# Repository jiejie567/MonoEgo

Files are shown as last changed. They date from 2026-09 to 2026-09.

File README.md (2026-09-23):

<div align="center">

# MonoEgo
**Monocular Metric Egocentric Demonstration Capture with Passive Wrist Constellations and Sparse Workstation Anchors**

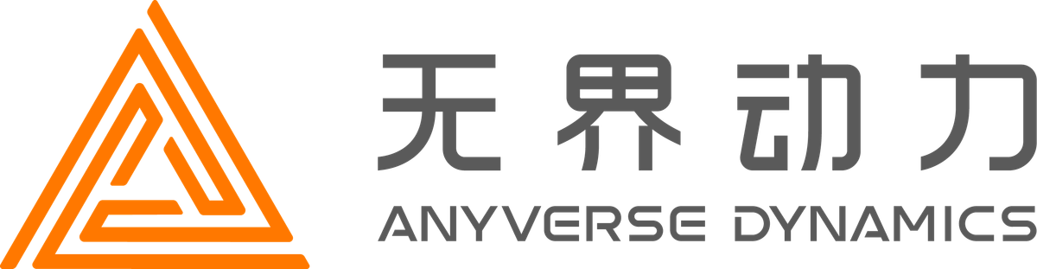
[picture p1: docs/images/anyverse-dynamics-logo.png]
Anyverse Dynamics


[Project homepage](https://jiejie567.github.io/MonoEgo/) · [MonoTag SLAM code](https://github.com/jiejie567/MonoTag-SLAM) · [Hardware](hardware/README.md) · [Results](results/README.md)

</div>

English | [中文](README_CN.md)

MonoEgo records human operations with a head-mounted RGB camera, two passive wrist fixtures and known-size workstation markers. Offline reconstruction produces metric camera and wrist-fixture trajectories from the same image stream.

The fixtures need no battery, IMU or radio. Video and geometric observations share one image clock, avoiding separate tracker-to-video synchronization. Camera and wrist-constellation calibration are still required.

This public repository contains hardware, compact experimental results and representative demonstrations. Public processing code is maintained separately in [MonoTag SLAM](https://github.com/jiejie567/MonoTag-SLAM).

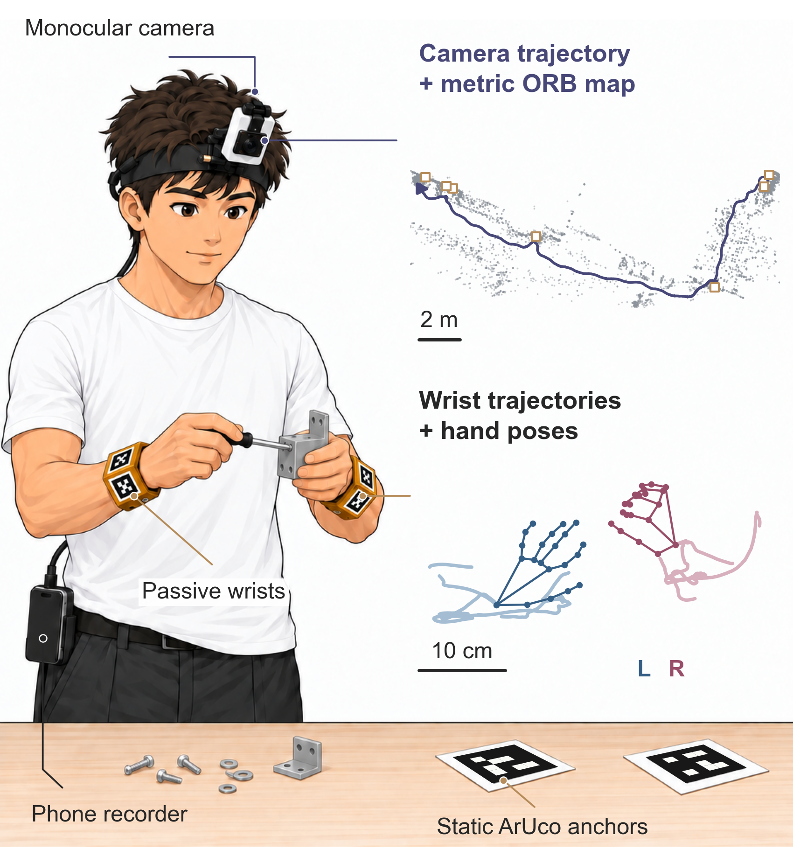
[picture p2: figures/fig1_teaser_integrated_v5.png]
MonoEgo capture system


## From recording to trajectories

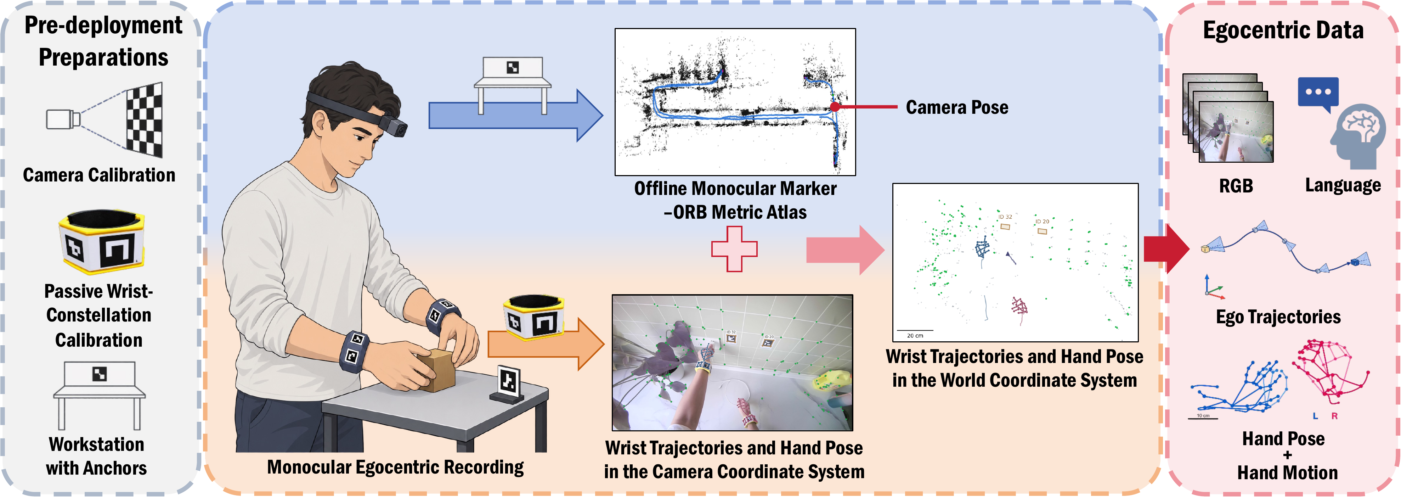
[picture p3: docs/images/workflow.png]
Calibration, recording and offline reconstruction


1. Print and assemble the fixtures and markers; verify physical dimensions.
2. Calibrate camera intrinsics and rigid wrist-marker geometry.
3. Record unchanged RGB video.
4. Run marker-constrained MonoTag reconstruction and optional hand estimation.
5. Inspect validity, trajectories and map events before exporting data.

Known marker dimensions provide metric information. Repeated views constrain scale and map consistency. Offline matching can recover earlier or short-gap poses when sufficient evidence exists. Appearance-edited RGB remains a separate derived product and never feeds back into localization.

## What's included

- [Printable hardware](hardware/README.md): magnetic wrist fixtures, marker sheets and ChArUco target.
- [Example calibrated layouts](hardware/marker_layouts/calibrated_release/): geometry of the specific tested fixtures, not a substitute for calibrating a new assembly.
- [Result sources](results/README.md): camera-reference and stationary-wrist summaries.
- [Representative videos](videos/): stationary-fixture demonstrations with ORB features and trajectories.
- [Processing code](https://github.com/jiejie567/MonoTag-SLAM): calibration, capture, reconstruction, replay and optional export.

## Hardware

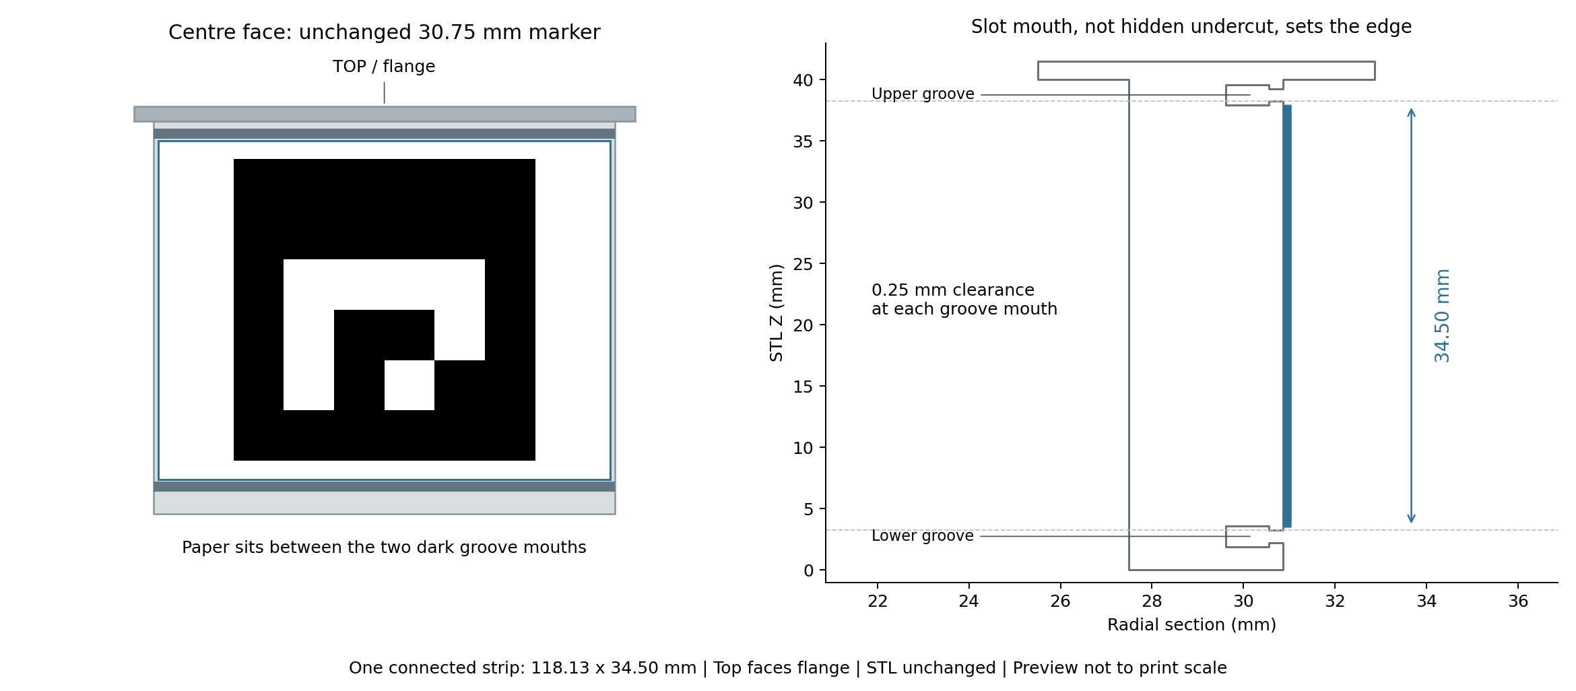
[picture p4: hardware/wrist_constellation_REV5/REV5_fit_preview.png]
REV5 marker placement between two rubber-band grooves


The default design is **REV5: two halves, two rubber-band grooves, no magnet holes**. Download the [STLs and matching marker sheets](hardware/wrist_constellation_REV5/). Add foam padding inside to fit different wrist sizes, and secure the seated halves with one rubber band in each groove. See the [assembly guide](hardware/README.md).

### Camera selection

No particular camera brand or model is required. Prioritize **high frame rate, manual exposure control, and a wide field of view** that covers both hands and enough surrounding scene. High FPS alone does not guarantee sharp frames: set a sufficiently short exposure for the motion and provide adequate light. Keep enough image detail for the wrist markers; a wider view is not automatically better if the markers become too small.

The tested setup uses a WN-L2406K397L global-shutter module, a 2.3 mm f/1.8 M12 lens and 1920 × 1080 recording at 90 FPS. This is a reference configuration, not a required purchase. Global shutter is preferable for rapid camera motion; alternative cameras are not guaranteed to match the reported results. Calibrate the chosen lens and recording mode, and keep focus, crop and stabilization settings unchanged during capture. Reconstruction uses measured intrinsics, not nominal field of view.

Reported capture-side cost was below US$100, excluding the recorder, replacement lens, offline compute, small fasteners and consumables, labour and shipping. This is not the cost of a complete recording and processing system.

Print at actual size, disable fit-to-page, and measure the black square rather than the white paper. Adjust foam thickness for a stable, comfortable fit without excessive pressure. Calibrate each newly assembled constellation.

## Representative videos

### Moving camera, stationary wrist fixtures

[SW-02 video](videos/SW-02_english_orb_trajectories.mp4)

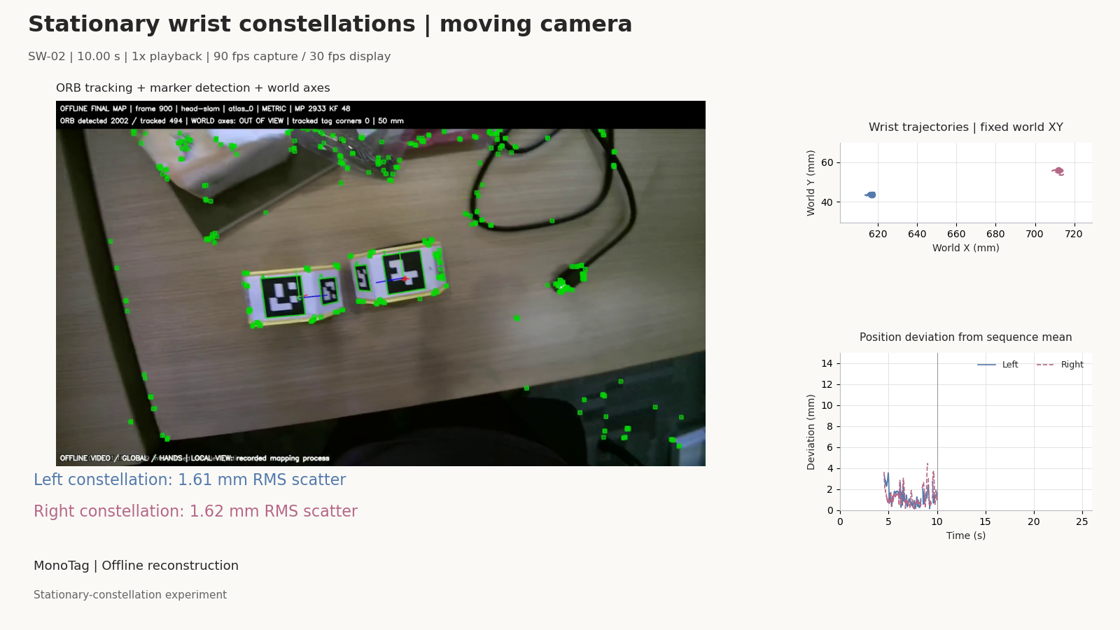
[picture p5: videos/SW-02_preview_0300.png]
SW-02 stationary wrist test


[SW-04 video](videos/SW-04_english_orb_trajectories.mp4)

These examples test whether camera motion appears as motion of a stationary fixture. They measure positional precision, not full dynamic hand-motion accuracy.

## Experimental scope

Camera motion is compared against Odin multisensor odometry as a reference. Metric error uses SE(3) alignment; Sim(3) results are separate because that alignment removes global scale error. Read error together with tracking coverage.

Across four stationary-wrist recordings, per-side RMS scatter was approximately 1.26–2.69 mm. This does not establish equivalent anatomical or dynamic accuracy. See [result sources](results/README.md) for the protocol and tables.

Raw indoor recordings, private screen content, machine-local paths and learned weights are excluded. The unblurred company-video review is not uploaded here.

## Getting started

Follow the [Ubuntu installation guide](https://github.com/jiejie567/MonoTag-SLAM/blob/main/docs/INSTALL.md). Start with SLAM and geometric wrist observations; learned hand inference and training-format export are optional.

## License

Original hardware, layouts, figures, result tables and documentation use [CC BY 4.0](LICENSE.md). Attribute **MonoEgo — Anyverse Dynamics** and indicate changes. Third-party material retains its original license. The company logo is excluded; no trademark or endorsement rights are granted.

Companion code uses GPL-3.0 because it includes modified ORB-SLAM3. Model and dataset terms still apply separately.

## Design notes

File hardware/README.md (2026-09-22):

# Hardware release

REV5 marker placement between rubber-band grooves

## Current design: REV5

Use [REV5 STLs and matching marker files](wrist_constellation_REV5/): two halves with two circumferential rubber-band grooves and **no magnet holes**. The older `wrist_constellation_v4/` magnetic design is retained only for historical reference, not as the default print.

- [Half A STL](wrist_constellation_REV5/REV5_strap_half_A_no_magnet_holes_full_loop_snap_in_rubber_grooves.stl)
- [Half B STL](wrist_constellation_REV5/REV5_strap_half_B_no_magnet_holes_full_loop_snap_in_rubber_grooves_xy_tight.stl)
- [Matching left/right marker strips — A4 PDF](wrist_constellation_REV5/REV5_groove_fit_connected_strips_A4.pdf)
- [Print preview](wrist_constellation_REV5/REV5_print_preview.png): preview only, print the PDF.
- Nominal CAD layouts: [left](wrist_constellation_REV5/strap_REV5_L_nominal.json), [right](wrist_constellation_REV5/strap_REV5_R_nominal.json). These are calibration starting points, not measured layouts.

## Assembly and fit

1. Print both halves at original scale. Remove sharp edges and check that the mating faces seat properly.
2. Attach soft foam padding inside. Adjust its thickness to fit the wearer's wrist without altering rigid shell geometry. Do not place foam between mating faces or force the shell open to fit a larger wrist.
3. Join the halves and put one rubber band in each circumferential groove. Check band retention and keep marker faces unobstructed. No magnets are required.
4. Fit should be stable and comfortable, without excessive pressure, pain or numbness. Stop wearing it if uncomfortable; a fixed shell cannot accommodate every wrist size.
5. Apply the matching strips between the grooves, following the printed top/flange and left/right labels. Avoid wrinkles or lifted corners. Calibrate each newly assembled constellation and recheck after changing stickers or assembly.

### 中文说明

护腕内部贴柔软海绵，通过厚度适配不同腕围。两瓣正确扣合后，上下两圈凹槽内各套一根橡皮筋固定，不需要磁铁。海绵不要夹进接缝，也不要为了容纳粗手腕而撑开外壳。佩戴应稳定、舒适、不勒手，疼痛或麻木时停止使用。贴纸位于两圈槽之间，橡皮筋不能遮挡码；重新装配或更换贴纸后进行腕带星座标定。

## Camera selection

The camera is not model-specific. Choose high-frame-rate recording, manual exposure control and a wide field of view covering both hands and background. Balance field of view with sufficient marker pixels, and use short exposure with adequate lighting. The tested 1080p/90-FPS global-shutter configuration is documented in the [main README](../README.md#camera-selection); it is not a mandatory model. Calibrate the actual lens and recording mode and keep image geometry stable during capture.

## Marker printing and calibration

Use the REV5 PDF at **100% / actual size**. Dictionary: `DICT_4X4_50`; small/large black squares: 21.5/30.75 mm. Verify black-square outer edges with a ruler. The connected strip is approximately 118.13 × 34.50 mm. The nominal JSON files retain their calibration warning; foam padding does not establish an anatomical wrist frame.

The older sheets in the root of `marker_layouts/` are legacy files. Prefer the matching REV5 PDF above; do not substitute older sheets without checking fit. The physical assembled constellation must be calibrated before quantitative capture; nominal JSON is not a substitute.

`marker_layouts/calibrated_release/` contains the measured rigid constellation geometry used for the reported final wrist experiments. These files reproduce that particular assembled pair of fixtures; they are not universal replacements for calibrating a newly printed and assembled fixture. Marker IDs and corner coordinates are unchanged from the experiment configuration, while local absolute source paths have been removed for anonymous release.

`marker_layouts/charuco_A4.pdf` is the camera-calibration target. Intrinsics are valid only for the same lens, focus, resolution, crop, stabilization, and camera mode used during calibration.

Original designs and layouts use [CC BY 4.0](../LICENSE.md). The accompanying
geometry describes marker fixtures, not anatomical hand calibration.

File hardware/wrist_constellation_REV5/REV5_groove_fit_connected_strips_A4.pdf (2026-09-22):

# REV5 / GROOVE-FIT WRIST STRIPS

A4: print 100% / Actual size. Disable Fit, Shrink and borderless expansion.

Each strip: 118.13 x 34.50 mm. Keep the black codes at their original size.

DICT_4X4_50 | side codes 21.50 mm | middle code 30.75 mm | one strip per shell half

L WRIST / HALF B - IDs 0, 1, 2

TOP / TOWARD FLANGE

ID 0 | ID 1 | ID 2
L WRIST / HALF A - IDs 3, 4, 5
| TOP / TOWARD FLANGE
ID 3 | ID 4 | ID 5
R WRIST / HALF B - IDs 6, 7, 8
| TOP / TOWARD FLANGE
ID 6 | ID 7 | ID 8
R WRIST / HALF A - IDs 9, 10, 11
| TOP / TOWARD FLANGE
ID 9 | ID 10 | ID 11

Cut only the outside rectangle. Start with the large code on the center flat.

Place BETWEEN the two groove mouths; leave 0.25 mm above and below the paper.

Keep TOP toward the flange/elbow. Leave 0.5 mm at each mating seam.

Do not let rubber bands cover the paper. Keep the full white margin; do not trim to the code.

Code sizes/IDs are unchanged. Sticker center is 0.75 mm higher: recalibrate after sticking.

This line must measure exactly 50 mm.

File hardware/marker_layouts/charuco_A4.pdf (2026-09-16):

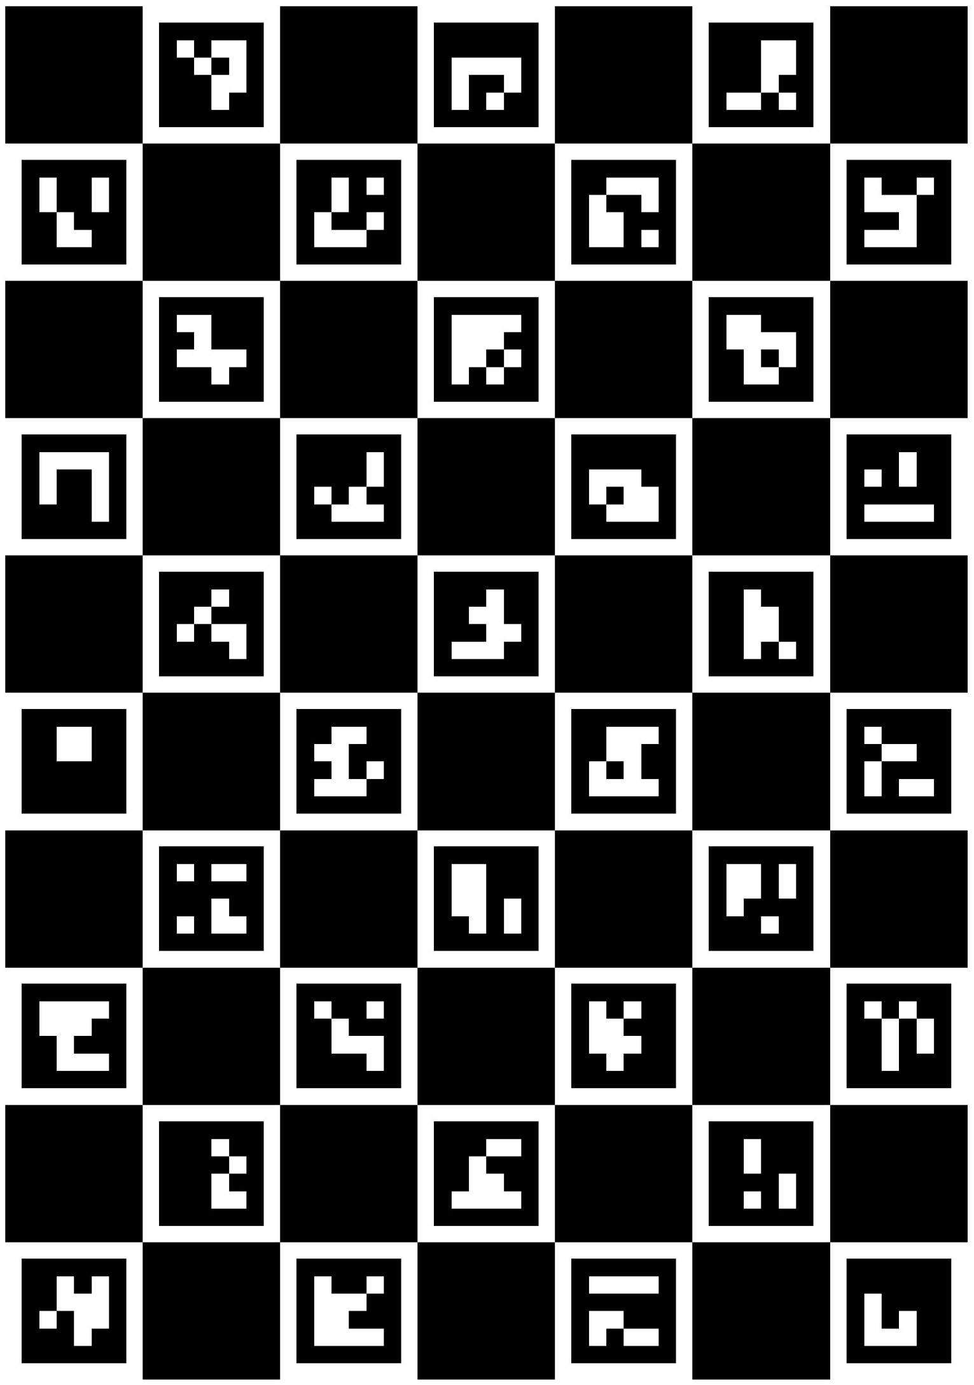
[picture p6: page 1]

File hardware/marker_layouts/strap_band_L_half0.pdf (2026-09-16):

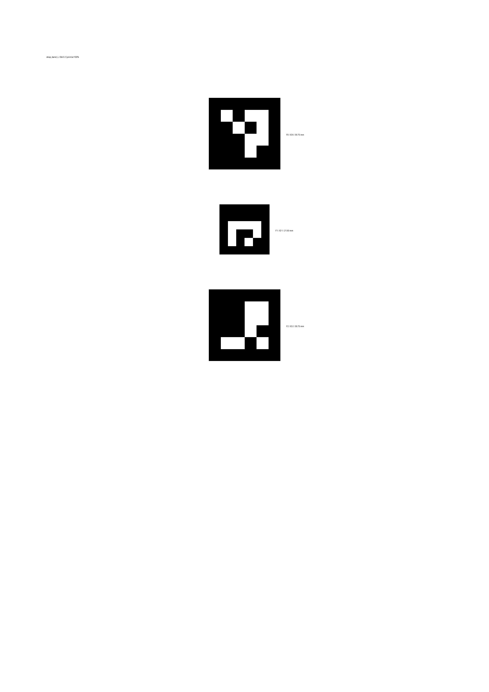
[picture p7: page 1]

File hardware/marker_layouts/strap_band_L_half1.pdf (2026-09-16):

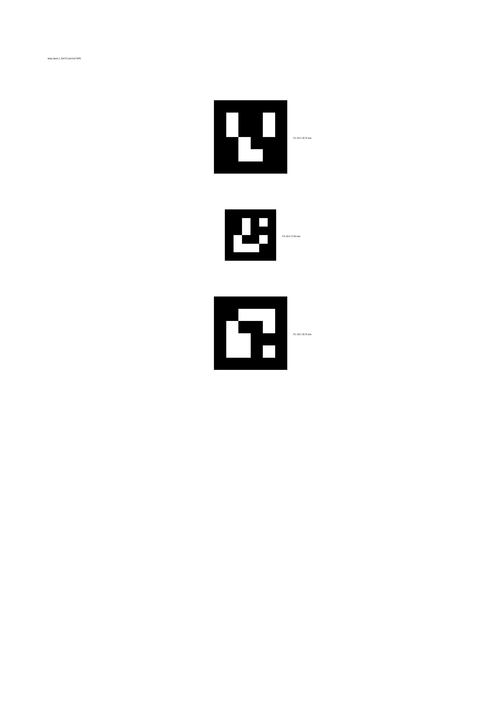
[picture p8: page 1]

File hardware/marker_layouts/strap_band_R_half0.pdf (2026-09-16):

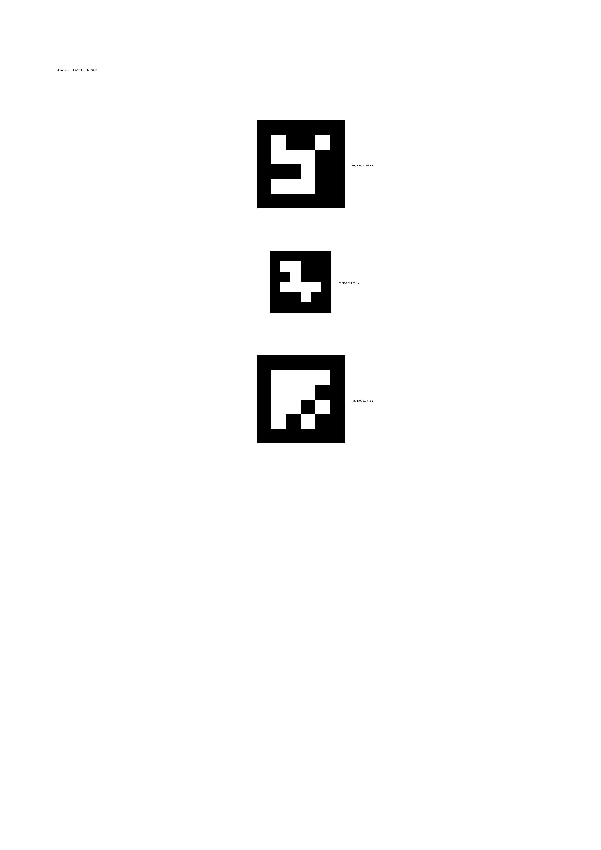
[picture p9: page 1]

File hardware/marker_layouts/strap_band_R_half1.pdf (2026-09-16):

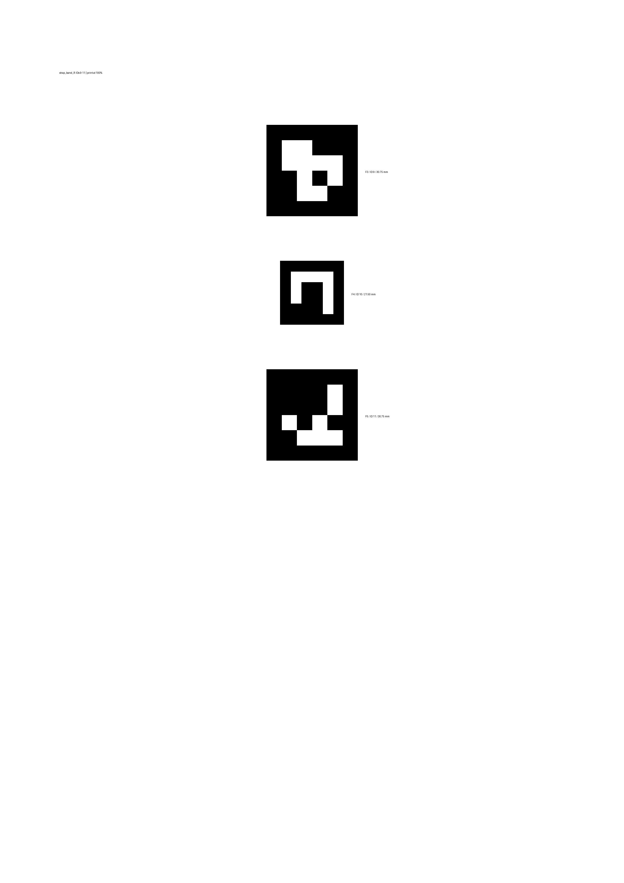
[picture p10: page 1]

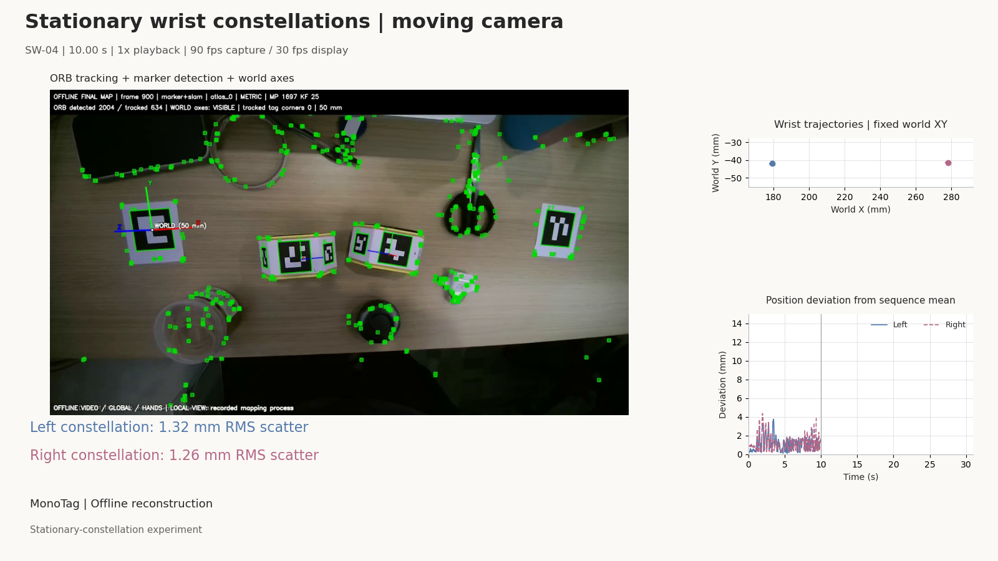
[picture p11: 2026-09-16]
videos/SW-04_preview_0300.png

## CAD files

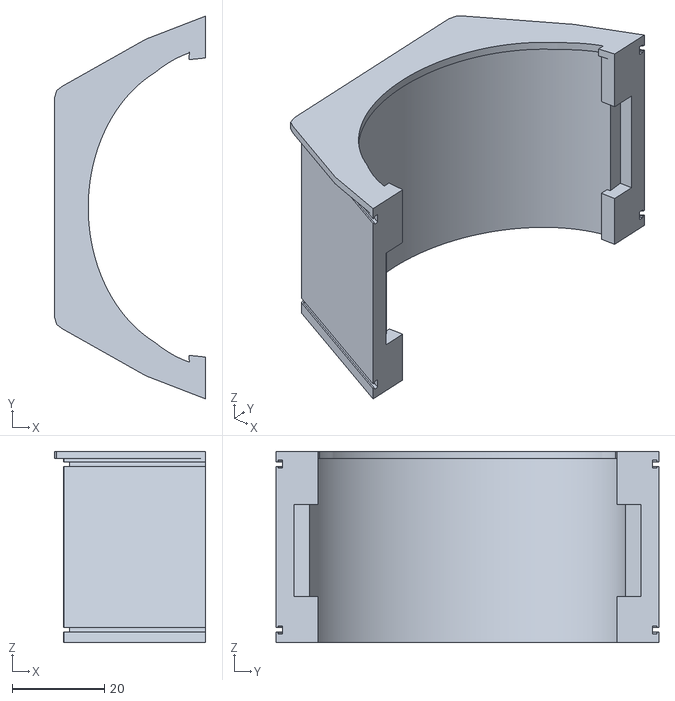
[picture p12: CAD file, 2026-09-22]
hardware/wrist_constellation_REV5/REV5_strap_half_A_no_magnet_holes_full_loop_snap_in_rubber_grooves.stl
32.9 x 83.2 x 41.5

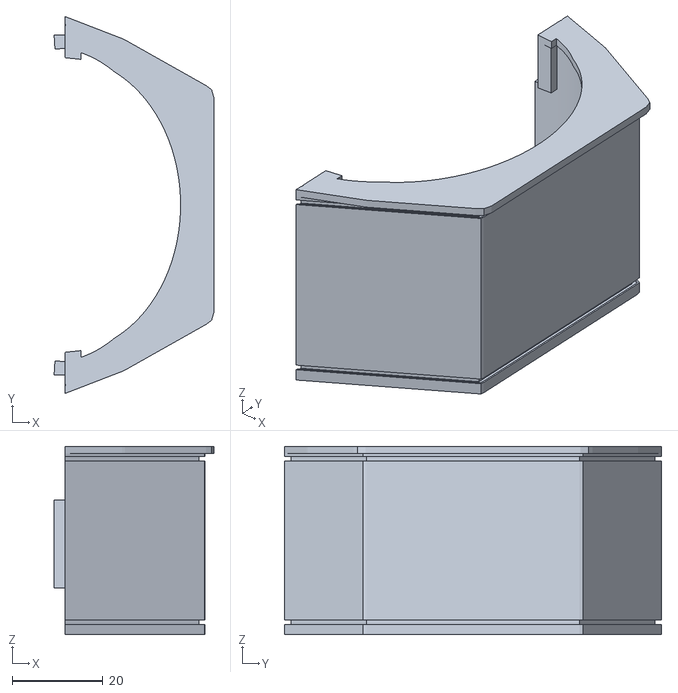
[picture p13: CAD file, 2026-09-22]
hardware/wrist_constellation_REV5/REV5_strap_half_B_no_magnet_holes_full_loop_snap_in_rubber_grooves_xy_tight.stl
35.3 x 83.2 x 41.5

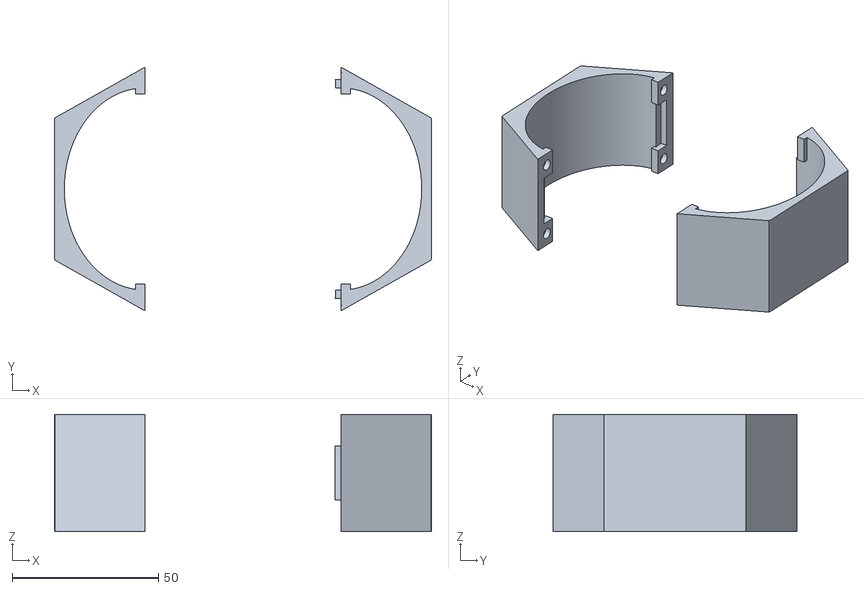
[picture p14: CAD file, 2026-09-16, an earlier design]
hardware/wrist_constellation_v4/strap_band_magnetic_no_velcro_print.stl
128.7 x 83.2 x 40.0

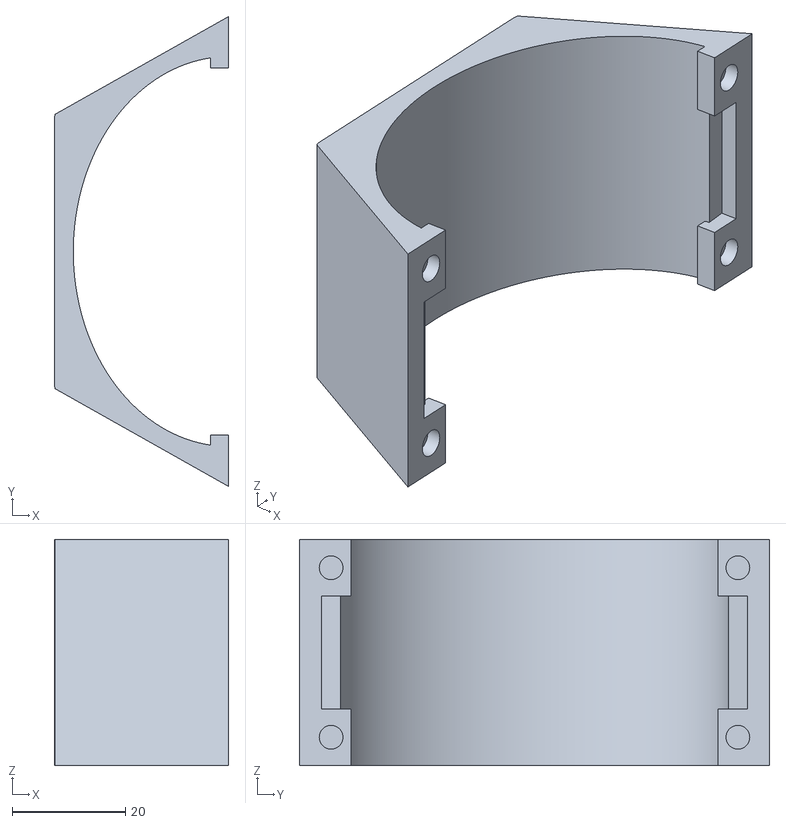
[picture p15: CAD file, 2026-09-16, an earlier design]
hardware/wrist_constellation_v4/strap_half_A_magnetic_no_velcro.stl
30.9 x 83.2 x 40.0

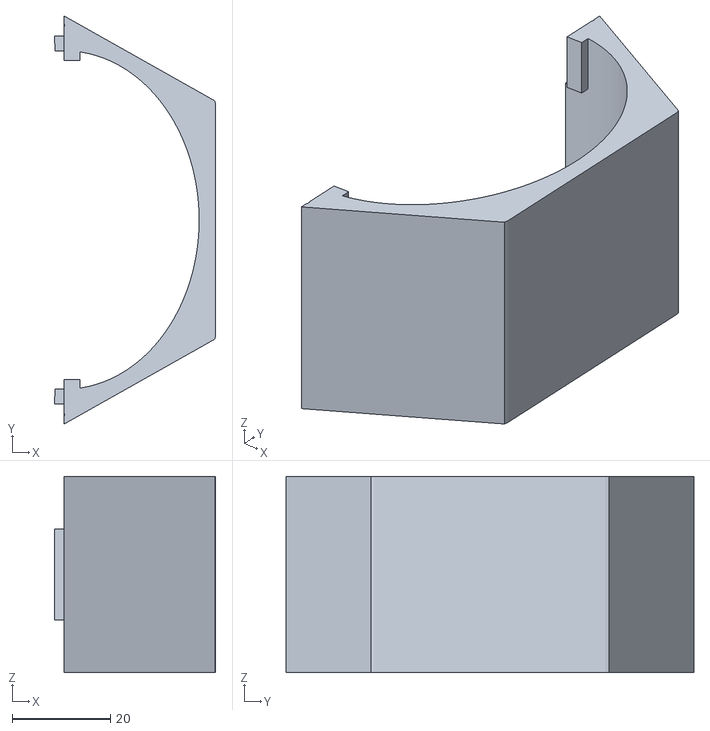
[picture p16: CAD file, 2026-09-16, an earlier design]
hardware/wrist_constellation_v4/strap_half_B_magnetic_no_velcro.stl
32.9 x 83.2 x 40.0

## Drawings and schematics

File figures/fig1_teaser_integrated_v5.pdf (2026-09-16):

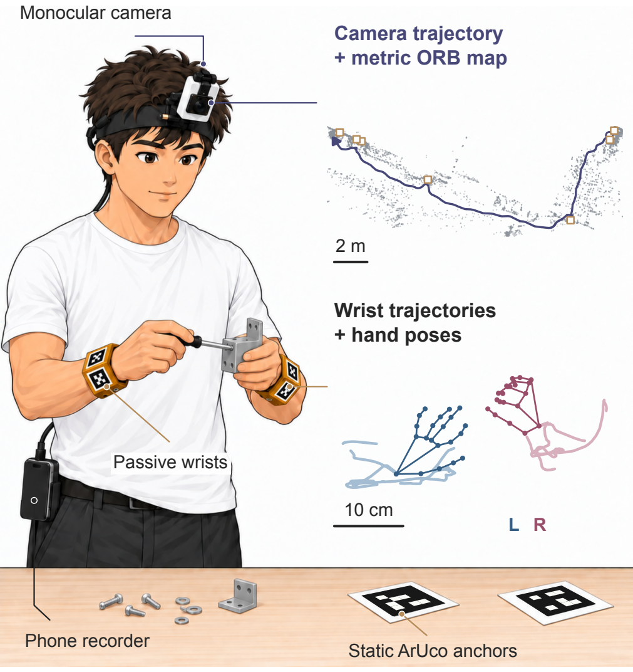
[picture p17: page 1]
Monocular camera; Wrist trajectories + hand poses; Passive wrists; Phone recorder; Static ArUco anchors

Camera trajectory
+ metric ORB map

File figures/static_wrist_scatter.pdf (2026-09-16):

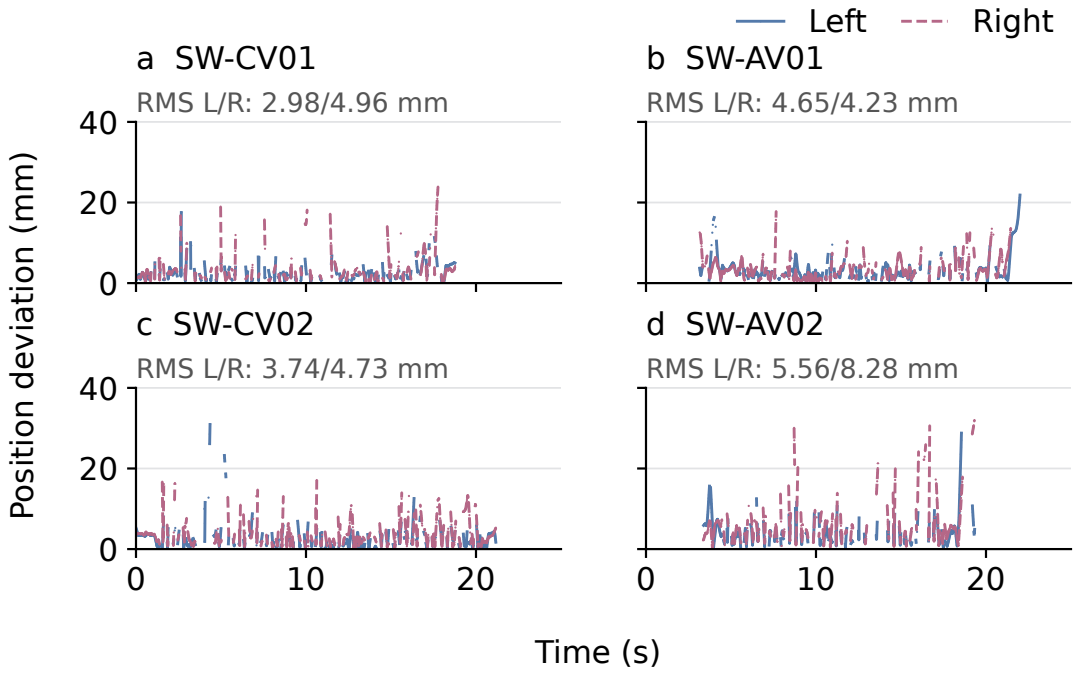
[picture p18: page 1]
40 RMS L/R: 2.98/4.96 mm; RMS L/R: 4.65/4.23 mm; 40 RMS L/R: 3.74/4.73 mm; RMS L/R: 5.56/8.28 mm; Time (s); Left; Right

Position deviation (mm)

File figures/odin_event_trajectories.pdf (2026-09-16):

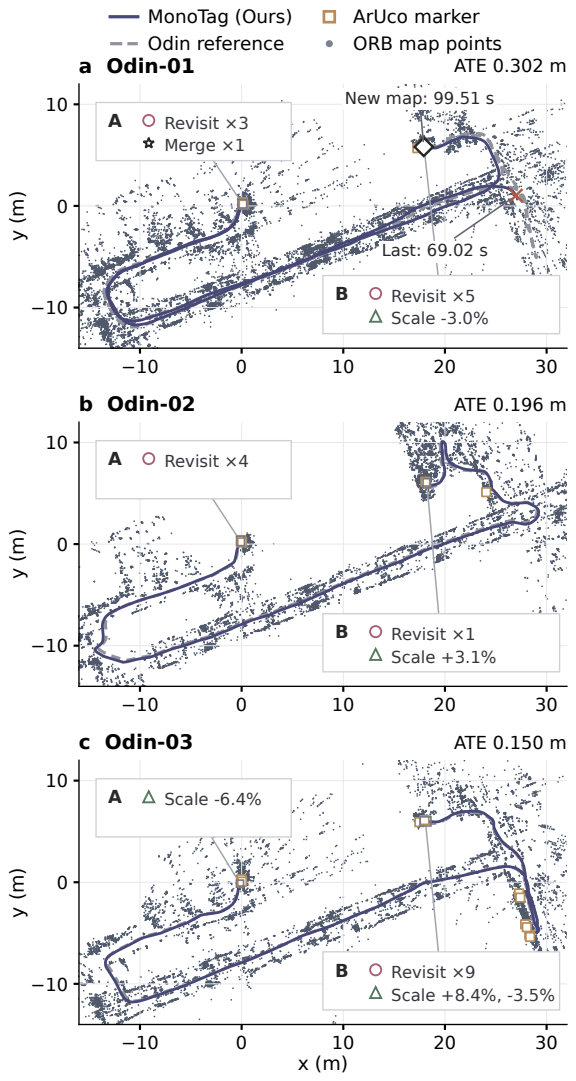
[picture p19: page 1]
a Odin-01; ATE 0.302 m; Last: 69.02 s; New map: 99.51 s; A Revisit ×3 Merge ×1; B Revisit ×5 Scale -3.0%; b Odin-02; ATE 0.196 m; A Revisit ×4; B Revisit ×1 Scale +3.1%; c Odin-03; ATE 0.150 m; A Scale -6.4%; B Revisit ×9 Scale +8.4%, -3.5%; MonoTag (Ours) Odin reference

ArUco marker
ORB map points

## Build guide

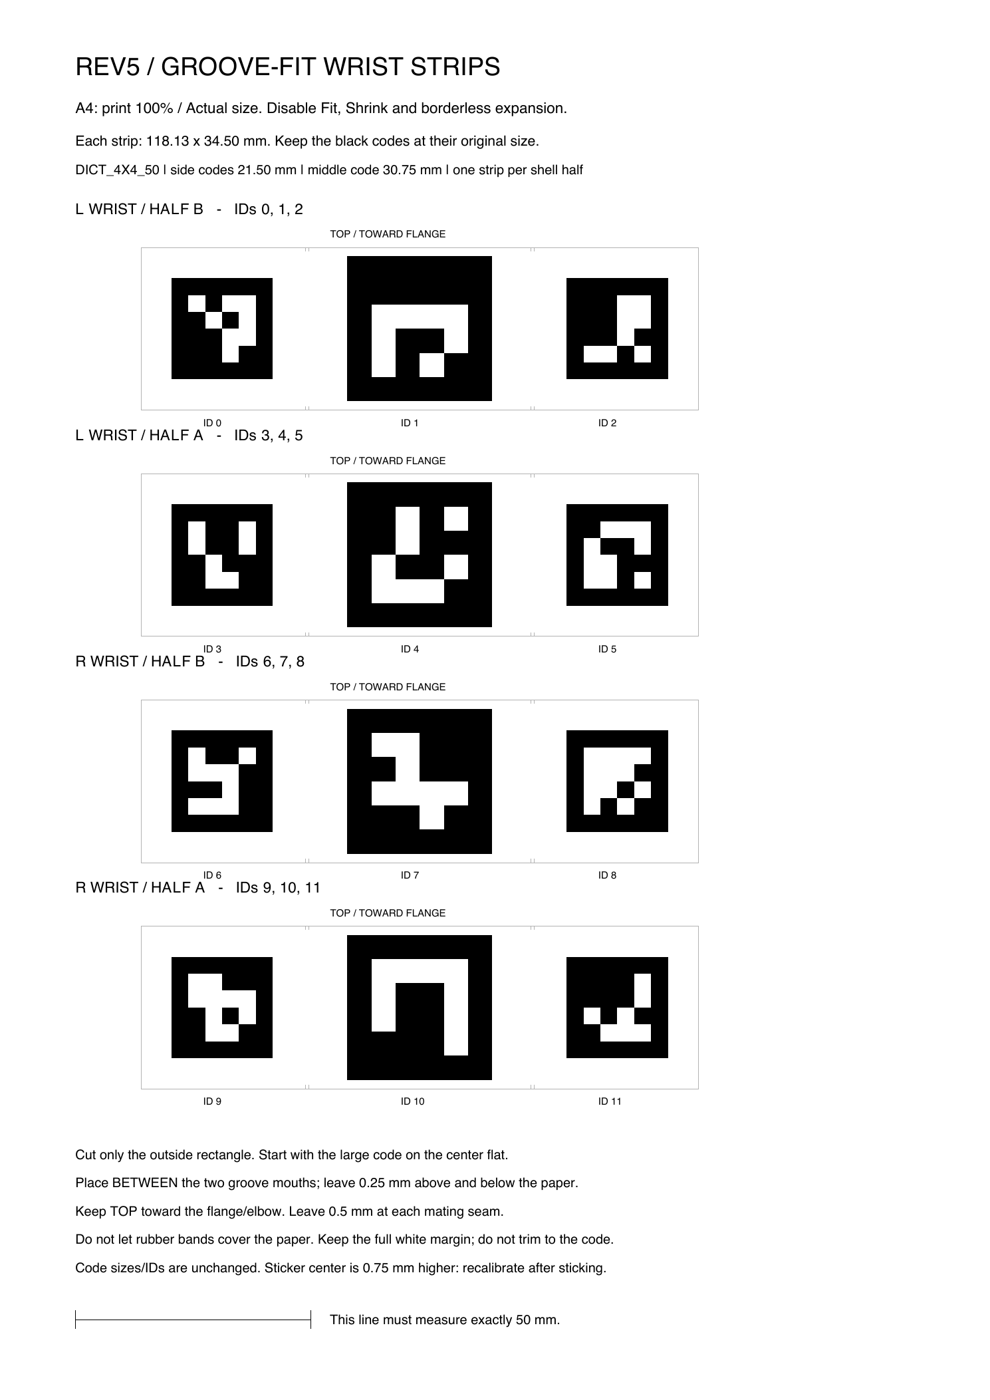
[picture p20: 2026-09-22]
hardware/wrist_constellation_REV5/REV5_print_preview.png

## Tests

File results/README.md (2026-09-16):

# Compact result sources

## Camera reference

`camera_reference/scores.csv` contains the compact method-by-sequence table used to generate the reported camera-reference comparison. `all_metrics.json` and `paired_support.json` preserve alignment and paired-support summaries without private filesystem paths or raw recordings.

Odin odometry is used only as a camera reference. MonoTag does not consume it during reconstruction. Metric methods are evaluated after SE(3) alignment; scale-free monocular baselines are additionally evaluated after Sim(3) alignment. Coverage must be read together with error.

## Stationary wrist constellations

`static_wrist/metrics.json` contains the four stationary-sequence precision summaries. RMS displacement and step statistics are descriptive precision measures. They are not absolute anatomical wrist accuracy, and missing observations are not converted into measurements.

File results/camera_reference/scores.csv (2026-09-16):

sequence | method | status | primary_map | metric | sparse | maps | samples | primary_map_coverage | output_fraction | wall_s | SE3_ATE_m | SE3_scale | SE3_RPE_1s_m | Sim3_ATE_m | Sim3_scale | Sim3_RPE_1s_m
143557 | ours_candidate | complete | atlas_0 | True | False | 2 | 2192 | 0.7834167262330236 | 0.7837741243745533 | 638.9292948070215 | 0.30156535165433696 | 1.0 | 0.027381083526386886 | 0.1702529022048756 | 1.0187982551589136 | 0.020005449459772673
143557 | ours_control | complete | atlas_0 | True | False | 2 | 2192 | 0.7834167262330236 | 0.7837741243745533 | 527.3579338729614 | 0.30156535165433696 | 1.0 | 0.027381083526386886 | 0.1702529022048756 | 1.0187982551589136 | 0.020005449459772673
143557 | marker-only | complete | map_24 | True | False | 7 | 452 | 0.16154395997140814 | 0.21658327376697642 | 1.5672277089906856 | 8.576886836917888 | 1.0 | 0.01791127444302918 | 1.9316377253538382 | 9.492275561928007 | 1.661097030074693
143557 | orb | complete | map_2 | False | False | 2 | 2415 | 0.8631165117941386 | 0.8884917798427449 | 199.3544694390148 |  |  |  | 7.703855094399215 | 0.5774783735522004 | 0.4002888042749345
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

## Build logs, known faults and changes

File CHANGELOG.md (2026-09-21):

# Release preparation — 2026-09-21

- Added English/Chinese README pages in the company project style.
- Added the company logo, workflow illustration and companion-code links.
- Retained the existing wrist-fixture STL, marker sheets, ChArUco target,
  calibrated example layouts, result tables and two review demonstrations.
- Added CC BY 4.0 terms for original hardware and documentation, with explicit
  exclusions for brand marks and third-party rights.
- Kept raw recordings and the unblurred publicity review outside the repository.

Repository visibility remains private. Public release, raw-video consent and
any broader media publication require a separate decision.

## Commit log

2026-09-16 Anonymous review materials
    [scores.csv, strap_band_magnetic_no_velcro_print.stl, strap_half_A_magnetic_no_velcro.stl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]
2026-09-22 docs: show magnetic wrist STL preview in READMEs
2026-09-22 hardware: release REV5 rubber-band wrist fixtures and matching markers
    [REV5_strap_half_A_no_magnet_holes_full_loop_snap_in_rubber_grooves.stl, REV5_strap_half_B_no_magnet_holes_full_loop_snap_in_rubber_grooves_xy_tight.stl]
2026-09-22 docs: mark MonoEgo materials as publicly available
2026-09-22 docs: describe model-independent camera selection priorities
